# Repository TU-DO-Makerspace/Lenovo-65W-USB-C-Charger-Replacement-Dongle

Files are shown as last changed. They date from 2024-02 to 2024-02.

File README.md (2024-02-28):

# How to fix a broken USB-C dongle on a Lenovo 65W Type C Charger

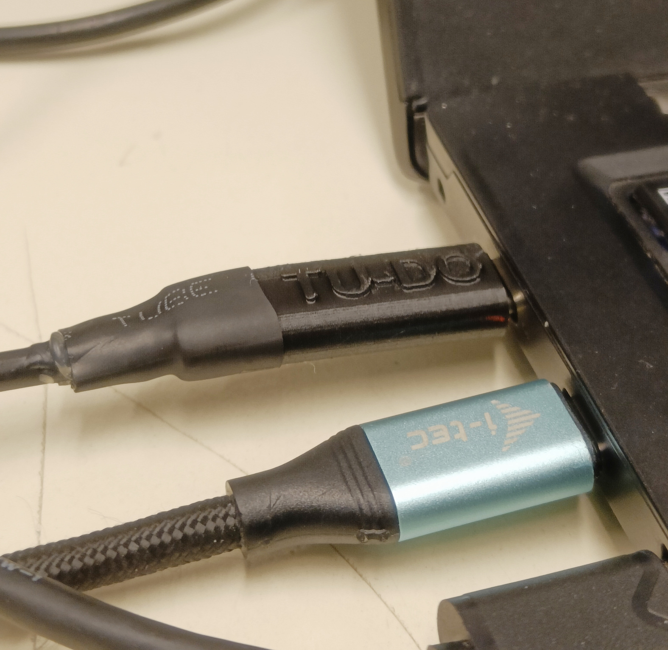
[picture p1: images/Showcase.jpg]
Showcase


This repository contains all the information you need to fix a broken USB-C dongle on a Lenovo 65W Type C Charger.

## Wiring

The Lenovo 65W Type C Charger uses a total of 3 wires for the USB-C dongle: VBUS, GND and CC1. The VBUS and GND wires are used to power the USB-C device, while the CC1 wire is used to negotiate the power delivery.

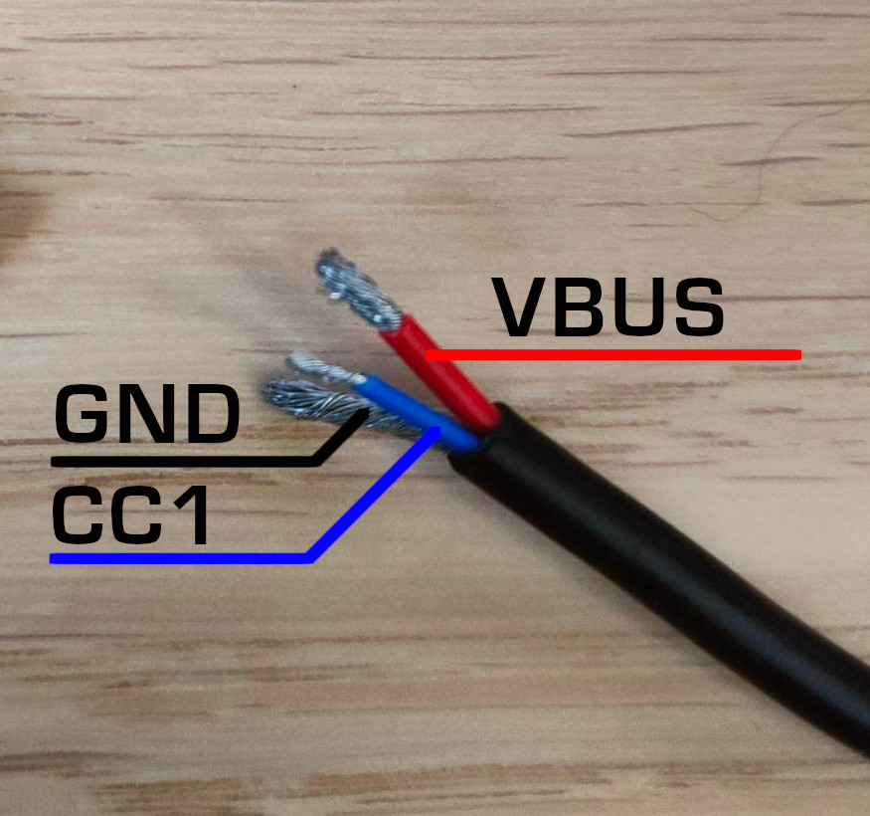
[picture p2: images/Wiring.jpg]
Wiring


Credits: https://superuser.com/questions/1770303/replace-male-usb-c-plug-in-lenovo-charger-cable

## Selecting a replacement USB-C dongle

The original USB-C dongle on the Lenovo 65W Type C Charger explicitly exposes the VBUS, GND and CC1 connections. Here's the nasty PCB left over from the broken original USB-C dongle

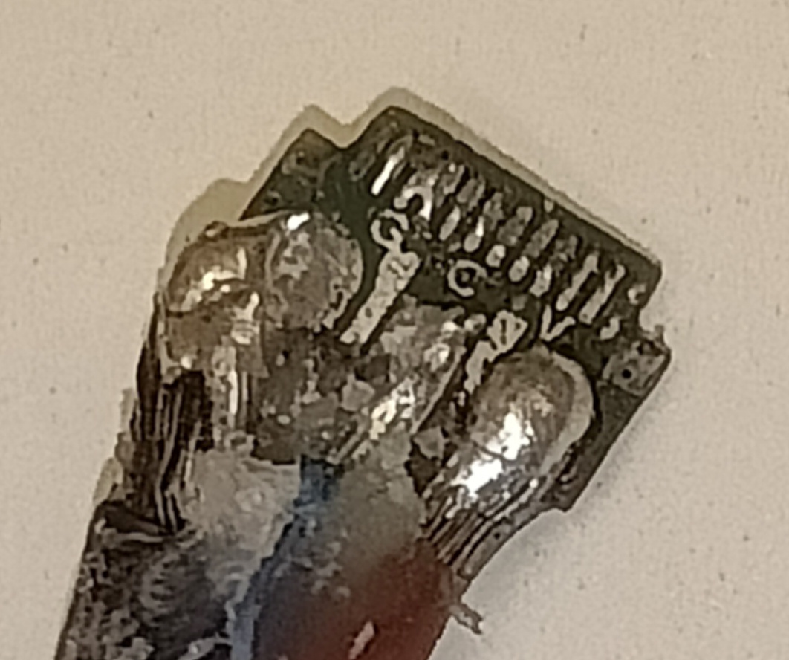
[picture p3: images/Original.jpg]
Original USB-C dongle


Unfortunately, most available USB-C dongles for soldering only expose the VBUS, D+, D- and GND connections. That being said, there's a simple hack to make them work as you'll see in the next section. For our fix we used the following USB-C dongle: www.aliexpress.com/item/1005005462430598.html

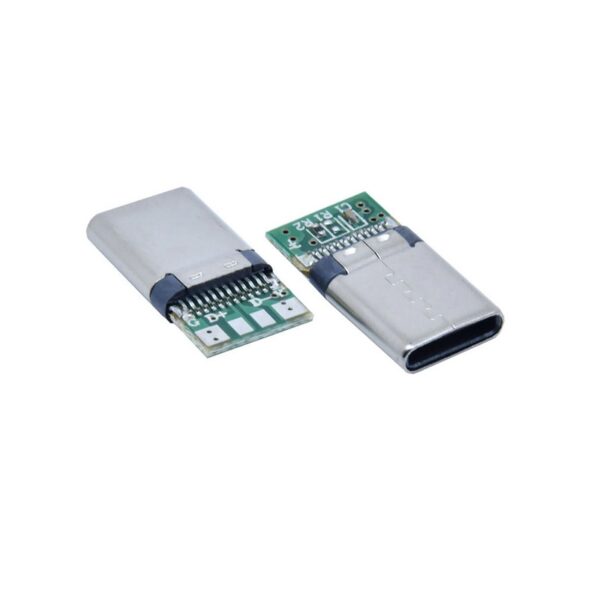
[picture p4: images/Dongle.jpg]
Replacement USB-C dongle


## Fixing the replacement USB-C dongle

Typically these solderable USB-C dongles have have a resistor (here marked R2) on the bottom side of the PCB that bridges VCC and CC1.

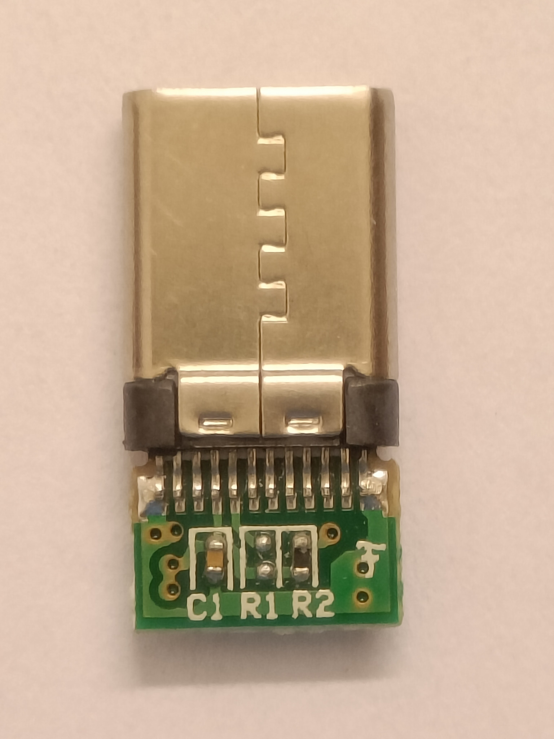
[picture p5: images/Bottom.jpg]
Replacement USB-C dongle bottom side


We can desolder this resistor and solder the blue wire onto the resistor's footprint instead. In addition to this, we need to cut the trace that connects one of the resistor's pad to VCC. The illustration below shows the necessary modifications:

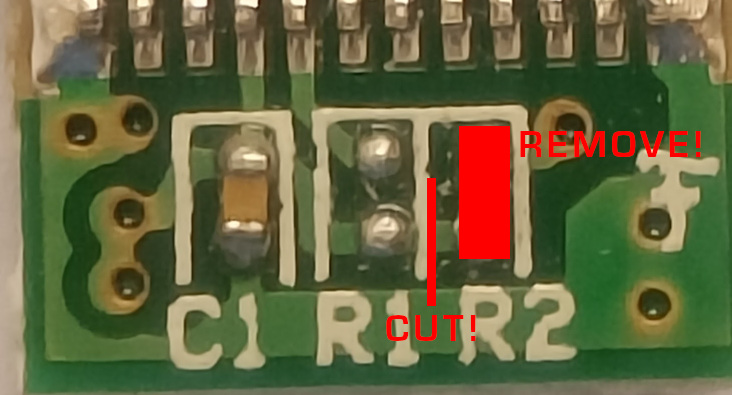
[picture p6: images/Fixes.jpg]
Replacement USB-C dongle modifications


## Soldering the USB-C dongle to the charger

On the "top" side, solder the shielding to the G(ND) pad, the red wire to the V(BUS) pad. On the bottom side, solder the blue wire to the pads for R2.

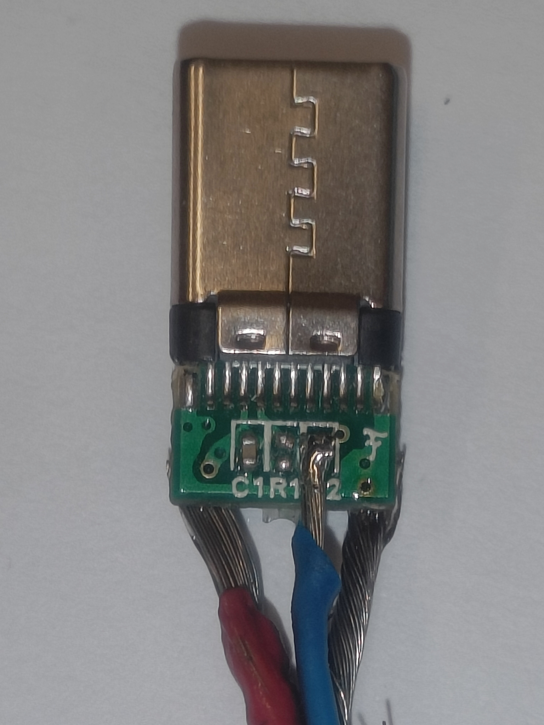
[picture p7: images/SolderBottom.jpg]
Replacement USB-C dongle modifications Bottom

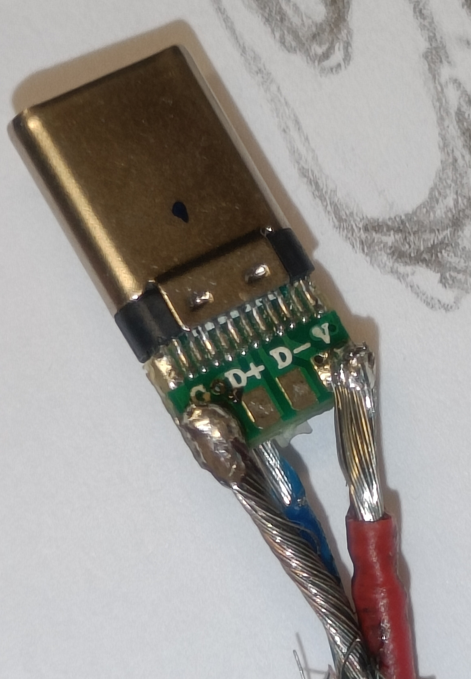
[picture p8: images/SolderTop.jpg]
Replacement USB-C dongle modifications Top


Make sure that there's no risk of short-circuiting the VBUS and GND wires. This can happen easily since the shielding is completely exposed.

## Enclousure

Self-soldered dongles can break pretty easily. To relieve the mechanical stress on the solder joints and wires, we created a 3D printable enclosure. The 3MF files are included in this project's repository.

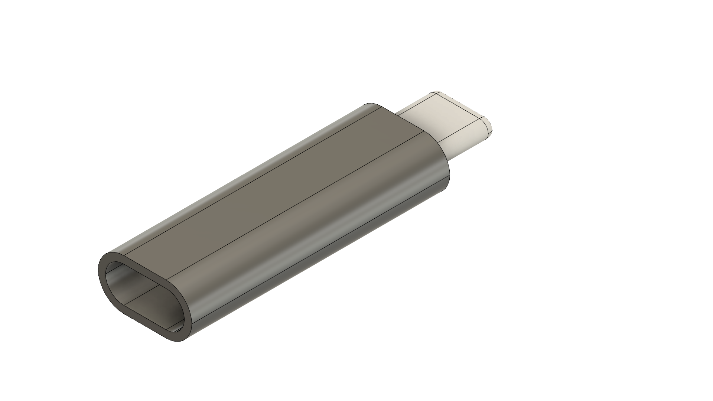
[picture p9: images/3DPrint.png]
Enclosure


One version has the "TU-DO" label on it, the other one is blank.

## Label

We also created a label with a QR code that links to this repository. This way, if the dongle breaks, the user can easily find the instructions to fix it!

Label

The SVG and PDF files for the label are also included in this project's repository.

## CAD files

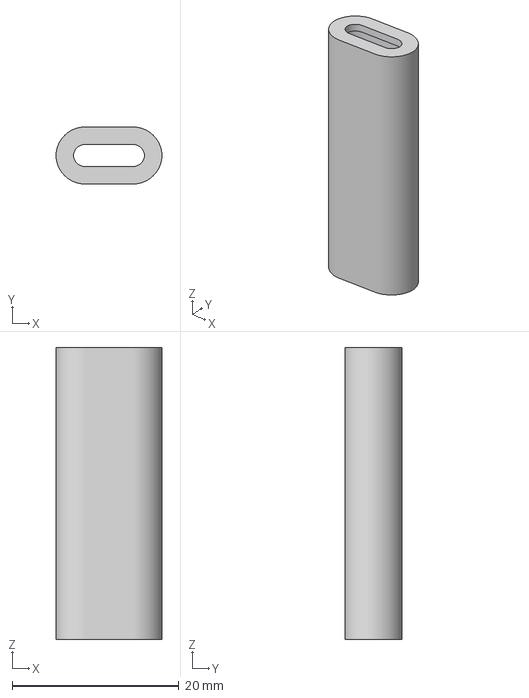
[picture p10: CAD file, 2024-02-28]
Type-C-Dongle.3mf
12.7 x 6.84 x 35.0 mm

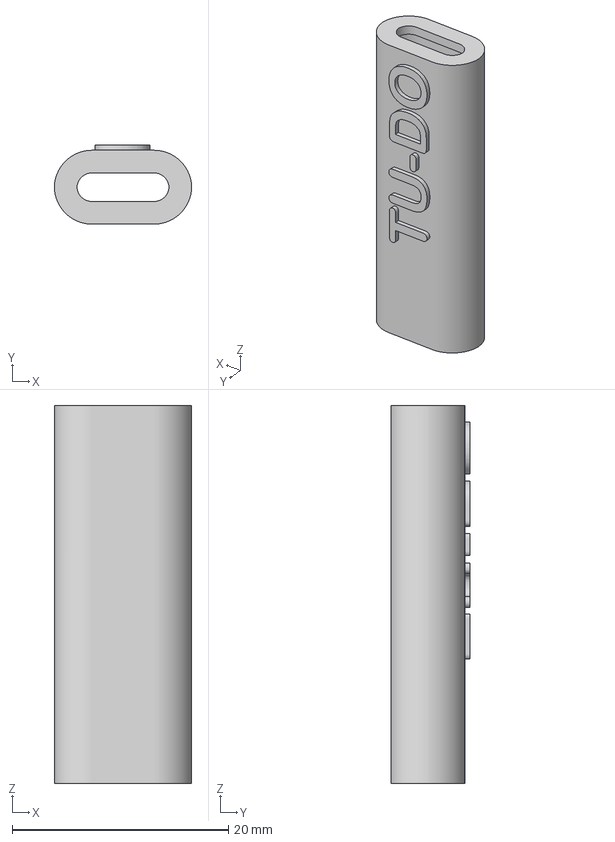
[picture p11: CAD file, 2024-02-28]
Type-C-Dongle_TU-DO.3mf
12.7 x 7.34 x 35.0 mm
